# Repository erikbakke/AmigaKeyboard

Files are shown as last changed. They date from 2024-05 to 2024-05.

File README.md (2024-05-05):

# AmigaKeyboard
Replacement keyboard supporting MX-compatible switches, for all Amigas except A600 and A1200.

This keyboard design is based around an ATMega32U4 as keyboard controller, and is intended to be used as a replacement keyboards for Amigas with a keyboard controller on the keyboard.  This includes the A500, A1000, A2000, A3000 and A4000, including variants and towers.

The A600 and A1200 have the keyboard controller on the motherboard, and are not compatible with this keyboard design.

There are further notes in the Firmware and PCB folders, relevant to those parts of the project.

It should be noted that this is an early design, but I have built a keyboard up from scratch with this PCB and firmware and it is working on my A4000.
The design is not yet designed to fit into existing Amiga keyboard cases or as a 1:1 replacement for an A500 keyboard.  In order to achieve this, the mounting holes need to be adjusted to fit the external keyboard cases, and most likely a switch mounting plate will also be required.
To avoid disappointment, please keep this in mind before ordering PCBs from this design.

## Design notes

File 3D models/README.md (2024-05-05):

# 3D models

This folder contains 3D models associated with the Amiga replacement keyboard project

| Model | Description |
| ----- | --- |
| Amiga MX key stem adapter | Quick hack to allow putting original Amiga key caps on top of MX-compatible switches.  The keys are raised by about 7mm compared to a directly mounted key cap, so it may interfere with a keyboard case. |

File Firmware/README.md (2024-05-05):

# AmigaKeyboard firmware

This folder contains the firmware source code for the Amiga replacement keyboard project.

The firmware is written in C as an Atmel Studio project and maintained in the current version (Microchip Studio 7).
I have not found any protocol timing issues during the testing of the firmware, and I have used this with my A4000 for over a year without any problems.
However, that doesn't mean there are no problems when used with other Amiga models, so if any problems are found I am happy to rewrite the relevant sections in AVR assembly code in order to achieve better control over the timing.
I would prefer to keep parts of the code that are not timing sensitive in C, though, to keep the code readable and understandable even for users who do not have AVR experience.

The AVR ATMega32U4 was chosen for this project as it has enough IO pins to run the keyboard matrix and it has a USB port which should make firmware upgrades and debugging easier.
The current version of the firmware does not yet take advantage of the USB port, though.  This is at the top of my todo-list at the moment.

It should be noted here that the keyboard matrix is not laid out identically to Commodore's matrix and that some keys which had dedicated lines in the Commodore design form part of the matrix in this design.
The use of diodes to support n-key rollover should remove the need for dedicated lines, and I have not yet experienced any issues related to this.
Even though the matrix is laid out differently the resulting scan codes are, of course, the same as in the original design.

## Operating principle

The matrix is scanned repeatedly by setting each row output low in turn and then checking each column inputs go low.
If a low is detected, the row/column combination is looked up in a table of scancodes.
The firmware tracks the status of each key and at the end of the matrix scan it will send down/up codes to the Amiga for any keys with a changed status.
The Caps Lock key is tracked separately, as this key toggles state each time it is pressed.

The communication with the Amiga is a custom serial protocol described in the Amiga Hardware Reference Manual (See Appendix G in HRM, 3rd revision).

## Missing features

- Ability to act as a USB serial port for debugging purposes.
- Support firmware updates over USB.
- Ability to act as a USB keyboard, which would allow use with any USB-capable computer.

## Firmware flashing process

I am using an Atmel ICE programmer, using the AVR-ISP programming plug.
On revision 0.1 of the PCB, I have to solder Dupont M-M wires to the PCB for each line required for the programming, and I connect the other end of the wires to the AVR-ISP plug.
With revision 0.2, there is a footprint for an AVR-ISP socket on the PCB, and each programming signal is routed to this footprint to make programming easier.

## Change log

Revision 0.1:
- Initial version of the firmware
- Incomplete debugging support

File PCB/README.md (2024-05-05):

# AmigaKeyboard PCB files

This folder contains the schematics and PCB design for revision 0.2 of the Amiga replacement keyboard design as a KiCad project.  This was initially developed in KiCad 6, and is currently maintained in KiCad 7.

The keyboard works as is with my A4000, but I have not yet had a chance to test it with my A500.  The design should be electrically compatible, and I'm hoping it would be dimensionally compatible as well.
Some work will be required to fit the PCB to existing Amiga external keyboard housings.  The current design has mounting holes to fit a keyboard case I had lying around, so I would be very happy to receive positions and dimensions for mounting holes on the different Amiga keyboards for A2000, A3000 and A4000 models, and will update the design in any way I can to increase compatibility.

I am getting PCBs manufactured from time to time and still have some revision 0.1 PCBs left if anyone want one for experimenting.

## Change log
Revision 0.1:
- Initial PCB version for prototype board manufacture.
  
Revision 0.2:
- A missing trace between D180 and MX80 (numeric pad "4") has been fixed.  The bodge wire fix is no longer needed on revision 0.2.
- Added AVR ISP connector to assist in firmware upgrades and troubleshooting.

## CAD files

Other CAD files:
3D models/Amiga MX key stem adapter/Amiga MX key stem adapter before cut.blend
3D models/Amiga MX key stem adapter/Amiga MX key stem adapter.blend

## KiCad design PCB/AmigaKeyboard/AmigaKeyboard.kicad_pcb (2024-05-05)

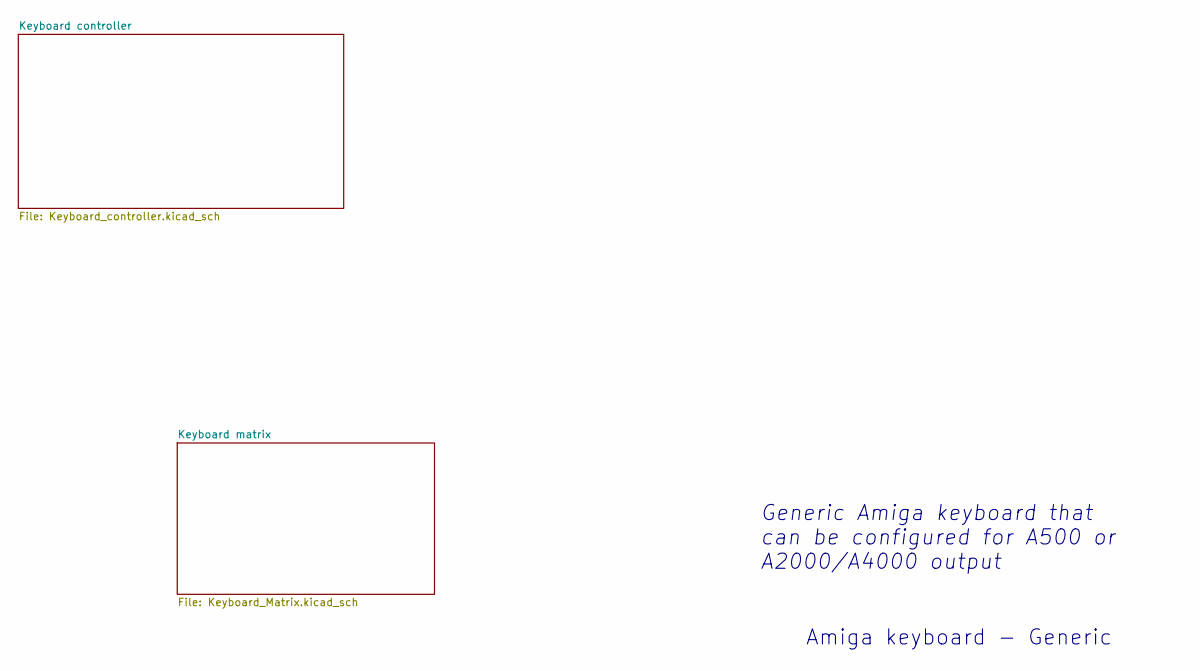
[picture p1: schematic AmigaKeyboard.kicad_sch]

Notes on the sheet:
Generic Amiga keyboard that can be configured for A500 or A2000/A4000 output
Amiga keyboard - Generic

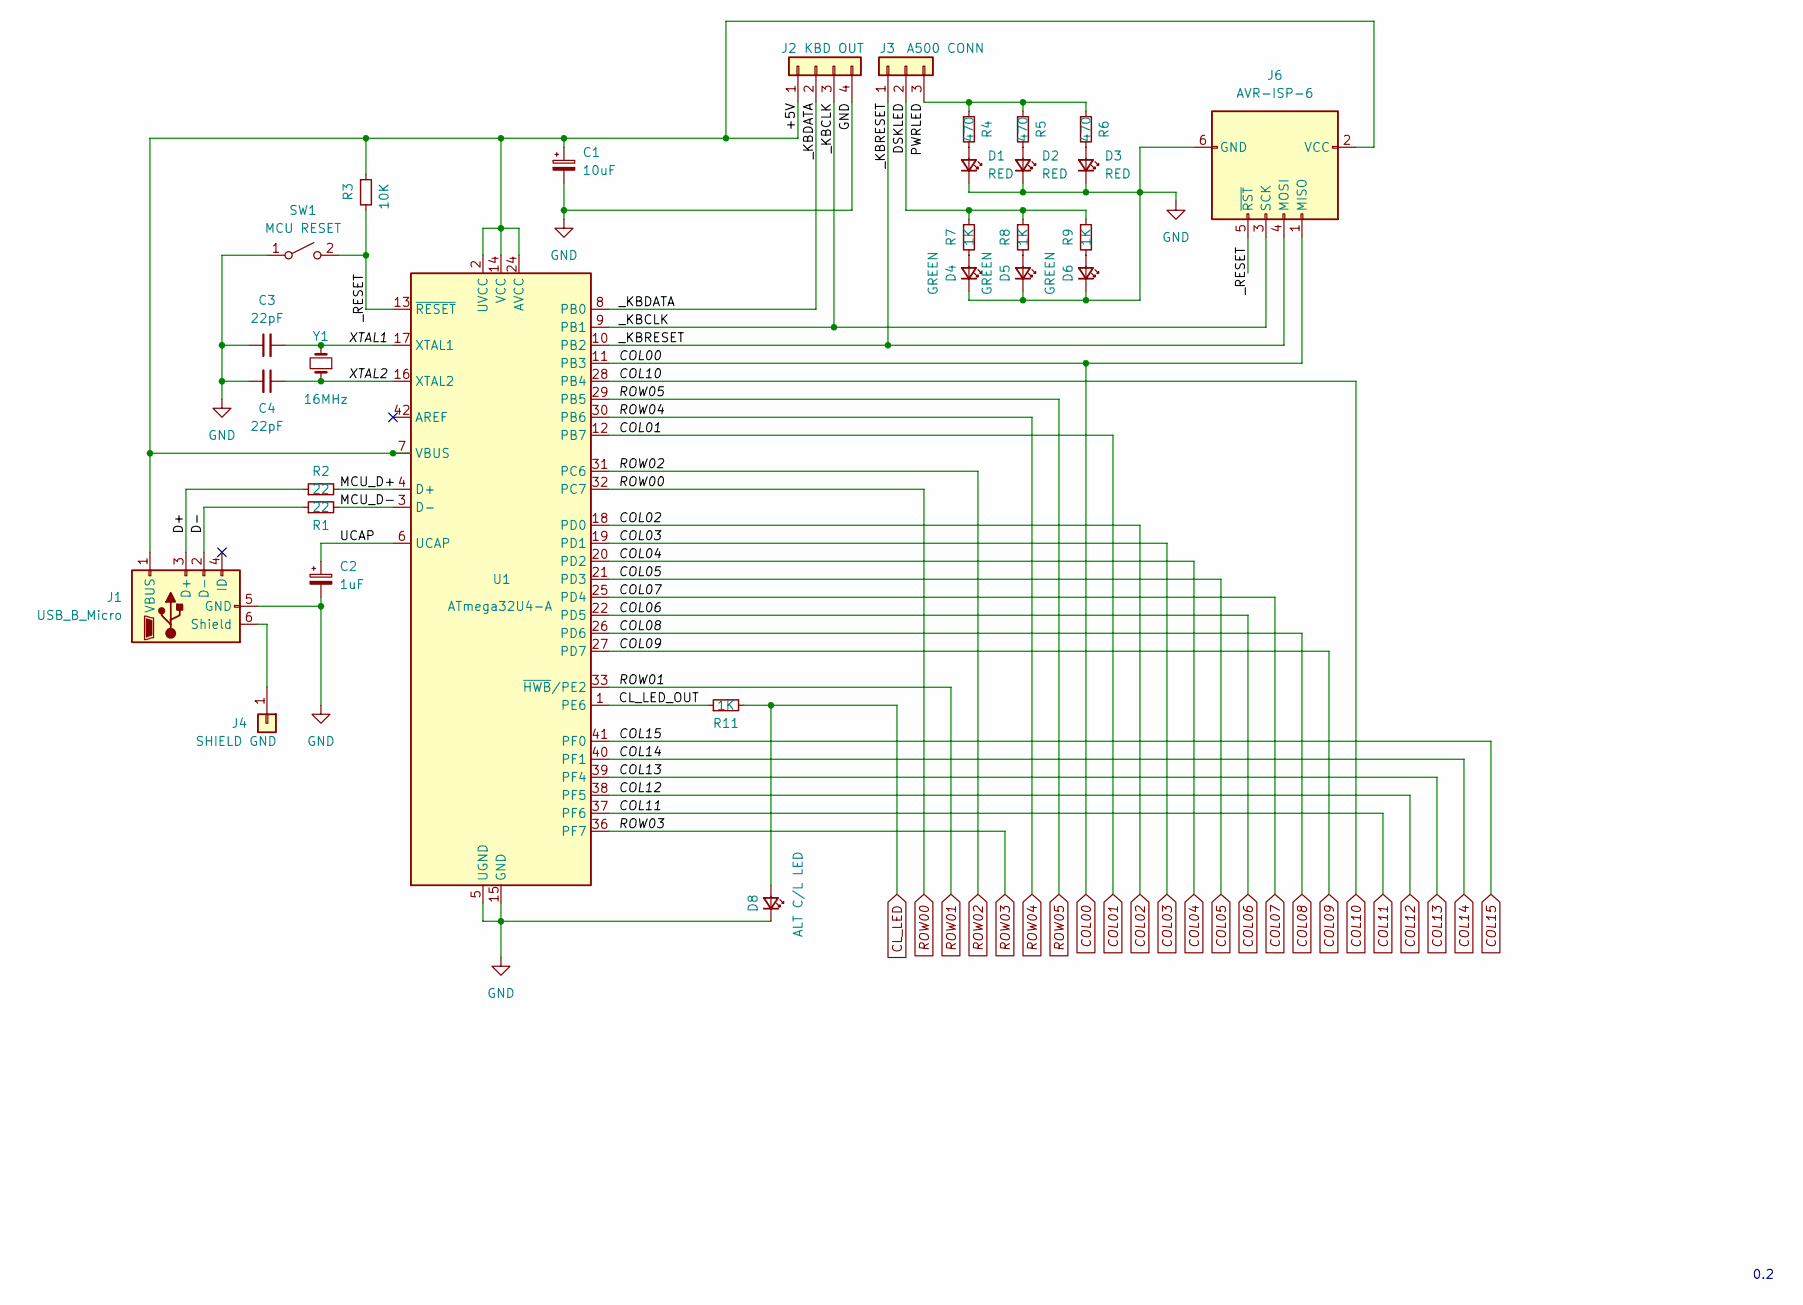
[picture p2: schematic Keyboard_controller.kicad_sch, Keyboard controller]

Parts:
C1: 10uF; CP_EIA-7343-31_Kemet-D
C2: 1uF; CP_EIA-3216-18_Kemet-A
C3, C4: 22pF; C_1206_3216Metric
D1, D2, D3: RED; LED_Rectangular_W5.0mm_H2.0mm
D4, D5, D6: GREEN; LED_Rectangular_W5.0mm_H2.0mm
D8: ALT C/L LED; LED_D3.0mm
J1: USB_B_Micro; USB_Micro-B_Wuerth_629105150521_CircularHoles
J2: KBD OUT; SolderWire-0.25sqmm_1x04_P4.2mm_D0.65mm_OD1.7mm
J3: A500 CONN; SolderWire-0.25sqmm_1x03_P4.2mm_D0.65mm_OD1.7mm
J4: SHIELD GND; SolderWire-2.5sqmm_1x01_D2.4mm_OD4.4mm
J6: AVR-ISP-6; PinHeader_2x03_P2.54mm_Vertical
R1, R2: 22; R_1206_3216Metric
R3: 10K; R_1206_3216Metric
R4, R5, R6: 470; R_1206_3216Metric
R7, R8, R9, R11: 1K; R_1206_3216Metric
SW1: MCU RESET; SW_PUSH_6mm
U1: ATmega32U4-A; TQFP-44_10x10mm_P0.8mm
Y1: 16MHz; Crystal_HC49-U_Vertical

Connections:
/Keyboard controller/+5V: C1.1, J1.1 (VBUS), J2.1, J6.2 (VCC), R3.1, U1.2 (UVCC), U1.7 (VBUS), U1.14 (VCC), U1.24 (AVCC), U1.34 (VCC), U1.44 (AVCC)
/Keyboard controller/CL_LED_OUT: R11.1, U1.1 (PE6)
/Keyboard controller/D+: J1.3 (D+), R2.1
/Keyboard controller/D-: J1.2 (D-), R1.1
/Keyboard controller/DSKLED: J3.2, R7.1, R8.1, R9.1
/Keyboard controller/MCU_D+: R2.2, U1.4 (D+)
/Keyboard controller/MCU_D-: R1.2, U1.3 (D-)
/Keyboard controller/PWRLED: J3.3, R4.1, R5.1, R6.1
/Keyboard controller/UCAP: C2.1, U1.6 (UCAP)
/Keyboard controller/XTAL1: C3.2, U1.17 (XTAL1), Y1.2
/Keyboard controller/XTAL2: C4.1, U1.16 (XTAL2), Y1.1
/Keyboard controller/_KBCLK: J2.3, J6.3 (SCK), U1.9 (PB1)
/Keyboard controller/_KBDATA: J2.2, U1.8 (PB0)
/Keyboard controller/_KBRESET: J3.1, J6.4 (MOSI), U1.10 (PB2)
/Keyboard controller/_RESET: J6.5 (~RST), R3.2, SW1.2 (B), U1.13 (~RESET)
CL_LED: D8.2 (A), R11.2; also elsewhere on the board
COL00: J6.1 (MISO), U1.11 (PB3); also elsewhere on the board
COL01: U1.12 (PB7); also elsewhere on the board
COL02: U1.18 (PD0); also elsewhere on the board
COL03: U1.19 (PD1); also elsewhere on the board
COL04: U1.20 (PD2); also elsewhere on the board
COL05: U1.21 (PD3); also elsewhere on the board
COL06: U1.22 (PD5); also elsewhere on the board
COL07: U1.25 (PD4); also elsewhere on the board
COL08: U1.26 (PD6); also elsewhere on the board
COL09: U1.27 (PD7); also elsewhere on the board
COL10: U1.28 (PB4); also elsewhere on the board
COL11: U1.37 (PF6); also elsewhere on the board
COL12: U1.38 (PF5); also elsewhere on the board
COL13: U1.39 (PF4); also elsewhere on the board
COL14: U1.40 (PF1); also elsewhere on the board
COL15: U1.41 (PF0); also elsewhere on the board
GND: C1.2, C2.2, C3.1, C4.2, D1.1 (K), D2.1 (K), D3.1 (K), D4.1 (K), D5.1 (K), D6.1 (K), D8.1 (K), J1.5 (GND), J2.4, J6.6 (GND), SW1.1 (A), U1.5 (UGND), U1.15 (GND), U1.23 (GND), U1.35 (GND), U1.43 (GND); also elsewhere on the board
unnamed: D1.2 (A), R4.2
unnamed: D2.2 (A), R5.2
unnamed: D3.2 (A), R6.2
unnamed: D4.2 (A), R7.2
unnamed: D5.2 (A), R8.2
unnamed: D6.2 (A), R9.2
unnamed: J1.6 (Shield), J4.1
ROW00: U1.32 (PC7); also elsewhere on the board
ROW01: U1.33 (~HWB/PE2); also elsewhere on the board
ROW02: U1.31 (PC6); also elsewhere on the board
ROW03: U1.36 (PF7); also elsewhere on the board
ROW04: U1.30 (PB6); also elsewhere on the board
ROW05: U1.29 (PB5); also elsewhere on the board

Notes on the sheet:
0.2

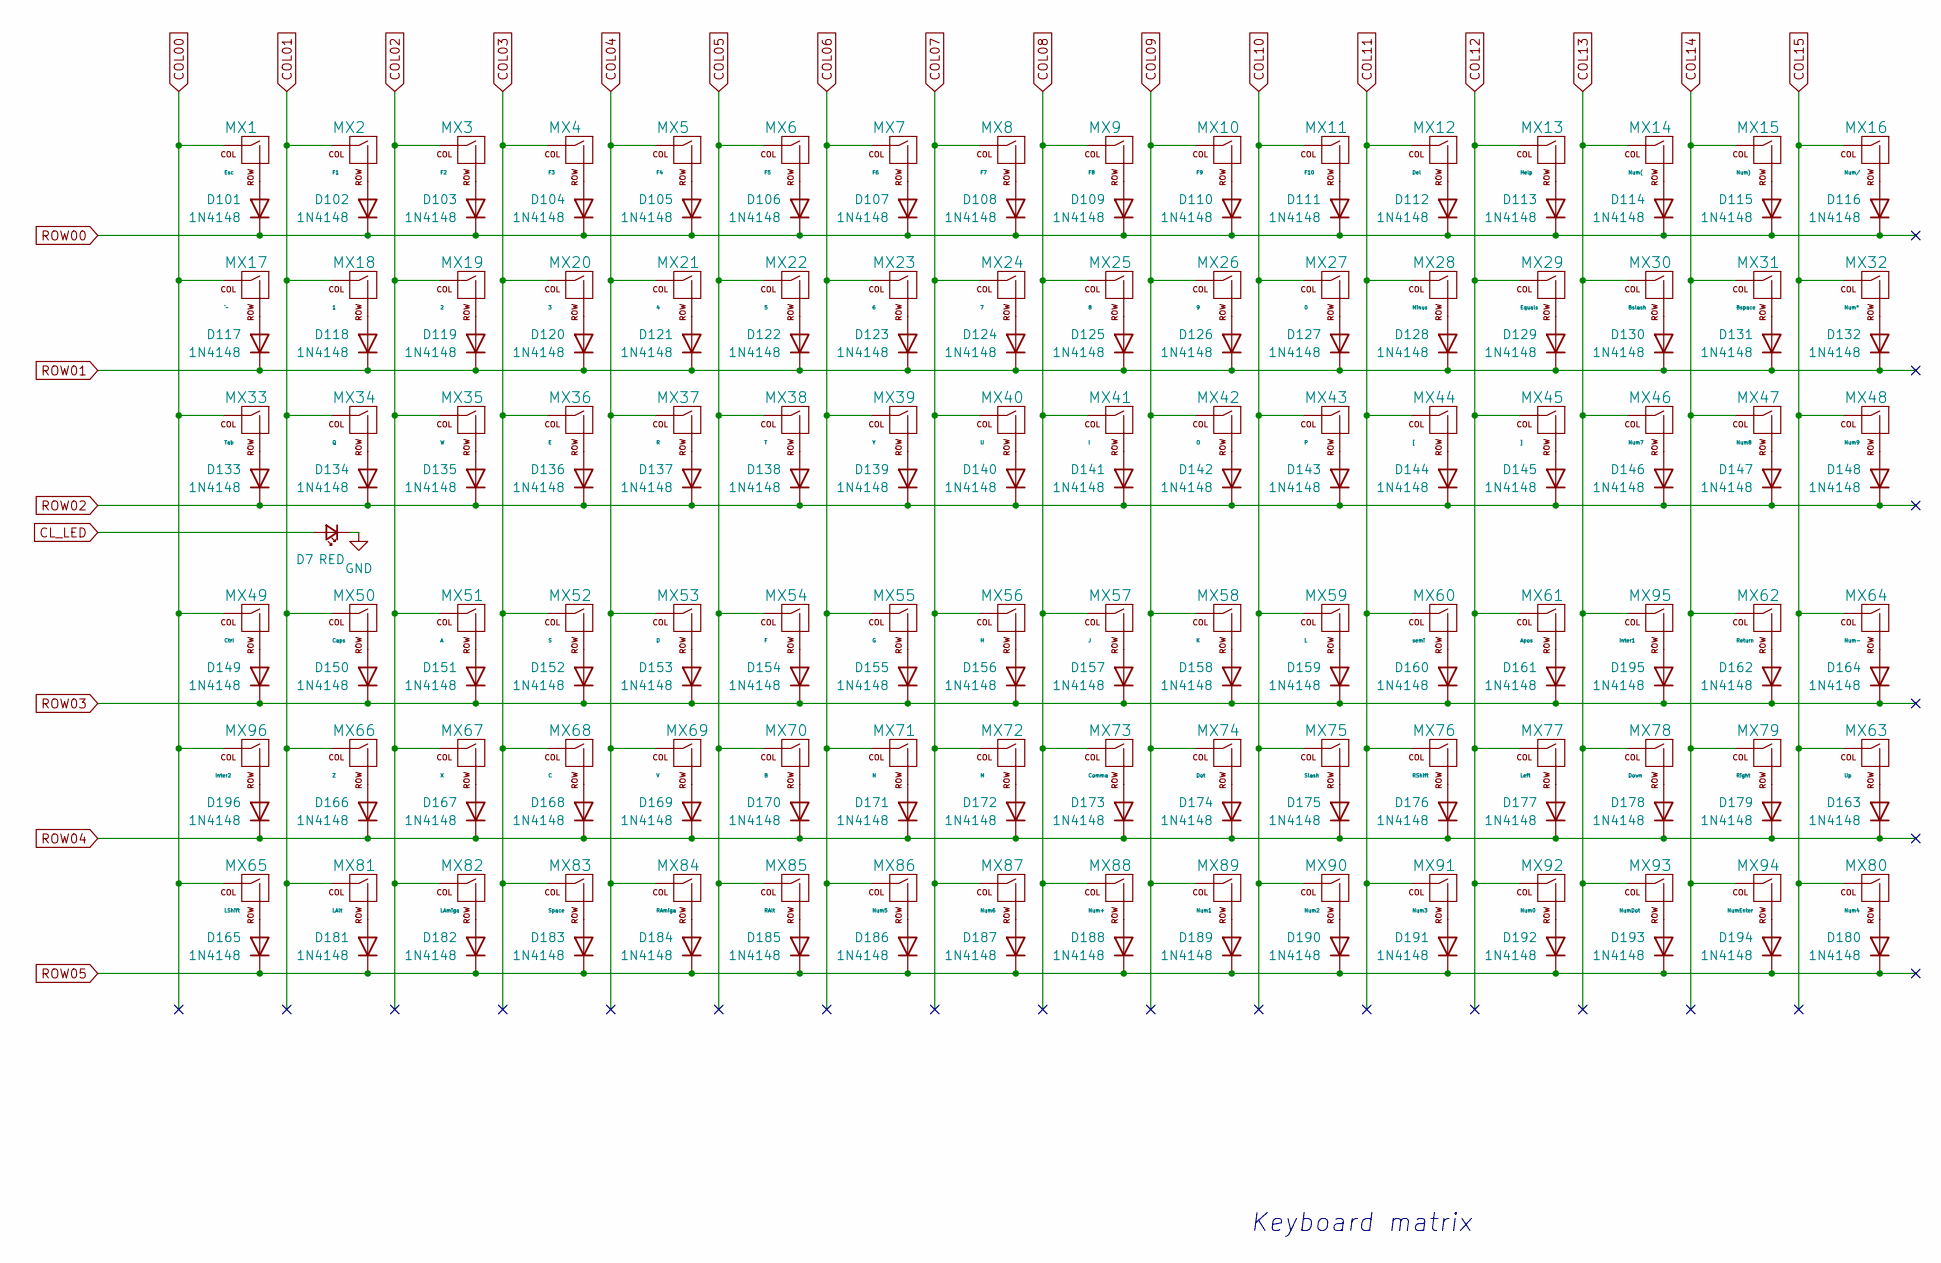
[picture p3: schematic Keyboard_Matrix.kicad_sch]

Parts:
D7: RED; LED_0805_2012Metric
D101, D102, D103, D104, D105, D106, D107, D108, D109, D110, D111, D112, D113, D114, D115, D116, D117, D118, D119, D120, D121, D122, D123, D124, D125, D126, D127, D128, D129, D130, D131, D132, D133, D134, D135, D136, D137, D138, D139, D140, D141, D142, D143, D144, D145, D146, D147, D148, D149, D150, D151, D152, D153, D154, D155, D156, D157, D158, D159, D160, D161, D162, D163, D164, D165, D166, D167, D168, D169, D170, D171, D172, D173, D174, D175, D176, D177, D178, D179, D180, D181, D182, D183, D184, D185, D186, D187, D188, D189, D190, D191, D192, D193, D194, D195, D196: 1N4148; D_0805_2012Metric_Pad1.15x1.40mm_HandSolder
MX1: Esc; SW_Cherry_MX_PCB_1.00u
MX2: F1; SW_Cherry_MX_PCB_1.25u
MX3: F2; SW_Cherry_MX_PCB_1.25u
MX4: F3; SW_Cherry_MX_PCB_1.25u
MX5: F4; SW_Cherry_MX_PCB_1.25u
MX6: F5; SW_Cherry_MX_PCB_1.25u
MX7: F6; SW_Cherry_MX_PCB_1.25u
MX8: F7; SW_Cherry_MX_PCB_1.25u
MX9: F8; SW_Cherry_MX_PCB_1.25u
MX10: F9; SW_Cherry_MX_PCB_1.25u
MX11: F10; SW_Cherry_MX_PCB_1.25u
MX12: Del; SW_Cherry_MX_PCB_1.50u
MX13: Help; SW_Cherry_MX_PCB_1.50u
MX14: Num(; SW_Cherry_MX_PCB_1.00u
MX15: Num); SW_Cherry_MX_PCB_1.00u
MX16: Num/; SW_Cherry_MX_PCB_1.00u
MX17: `~; SW_Cherry_MX_PCB_1.50u
MX18: 1; SW_Cherry_MX_PCB_1.00u
MX19: 2; SW_Cherry_MX_PCB_1.00u
MX20: 3; SW_Cherry_MX_PCB_1.00u
MX21: 4; SW_Cherry_MX_PCB_1.00u
MX22: 5; SW_Cherry_MX_PCB_1.00u
MX23: 6; SW_Cherry_MX_PCB_1.00u
MX24: 7; SW_Cherry_MX_PCB_1.00u
MX25: 8; SW_Cherry_MX_PCB_1.00u
MX26: 9; SW_Cherry_MX_PCB_1.00u
MX27: 0; SW_Cherry_MX_PCB_1.00u
MX28: Minus; SW_Cherry_MX_PCB_1.00u
MX29: Equals; SW_Cherry_MX_PCB_1.00u
MX30: Bslash; SW_Cherry_MX_PCB_1.00u
MX31: Bspace; SW_Cherry_MX_PCB_1.00u
MX32: Num*; SW_Cherry_MX_PCB_1.00u
MX33: Tab; SW_Cherry_MX_PCB_2.00u
MX34: Q; SW_Cherry_MX_PCB_1.00u
MX35: W; SW_Cherry_MX_PCB_1.00u
MX36: E; SW_Cherry_MX_PCB_1.00u
MX37: R; SW_Cherry_MX_PCB_1.00u
MX38: T; SW_Cherry_MX_PCB_1.00u
MX39: Y; SW_Cherry_MX_PCB_1.00u
MX40: U; SW_Cherry_MX_PCB_1.00u
MX41: I; SW_Cherry_MX_PCB_1.00u
MX42: O; SW_Cherry_MX_PCB_1.00u
MX43: P; SW_Cherry_MX_PCB_1.00u
MX44: [; SW_Cherry_MX_PCB_1.00u
MX45: ]; SW_Cherry_MX_PCB_1.00u
MX46: Num7; SW_Cherry_MX_PCB_1.00u
MX47: Num8; SW_Cherry_MX_PCB_1.00u
MX48: Num9; SW_Cherry_MX_PCB_1.00u
MX49: Ctrl; SW_Cherry_MX_PCB_1.25u
MX50: Caps; SW_Cherry_MX_PCB_1.00u
MX51: A; SW_Cherry_MX_PCB_1.00u
MX52: S; SW_Cherry_MX_PCB_1.00u
MX53: D; SW_Cherry_MX_PCB_1.00u
MX54: F; SW_Cherry_MX_PCB_1.00u
MX55: G; SW_Cherry_MX_PCB_1.00u
MX56: H; SW_Cherry_MX_PCB_1.00u
MX57: J; SW_Cherry_MX_PCB_1.00u
MX58: K; SW_Cherry_MX_PCB_1.00u
MX59: L; SW_Cherry_MX_PCB_1.00u
MX60: semi; SW_Cherry_MX_PCB_1.00u
MX61: Apos; SW_Cherry_MX_PCB_1.00u
MX62: Return; SW_Cherry_MX_PCB_ISOEnter
MX63: Up; SW_Cherry_MX_PCB_1.00u
MX64: Num-; SW_Cherry_MX_PCB_1.00u
MX65: LShift; SW_Cherry_MX_PCB_1.75u
MX66: Z; SW_Cherry_MX_PCB_1.00u
MX67: X; SW_Cherry_MX_PCB_1.00u
MX68: C; SW_Cherry_MX_PCB_1.00u
MX69: V; SW_Cherry_MX_PCB_1.00u
MX70: B; SW_Cherry_MX_PCB_1.00u
MX71: N; SW_Cherry_MX_PCB_1.00u
MX72: M; SW_Cherry_MX_PCB_1.00u
MX73: Comma; SW_Cherry_MX_PCB_1.00u
MX74: Dot; SW_Cherry_MX_PCB_1.00u
MX75: Slash; SW_Cherry_MX_PCB_1.00u
MX76: RShift; SW_Cherry_MX_PCB_2.50u
MX77: Left; SW_Cherry_MX_PCB_1.00u
MX78: Down; SW_Cherry_MX_PCB_1.00u
MX79: Right; SW_Cherry_MX_PCB_1.00u
MX80: Num4; SW_Cherry_MX_PCB_1.00u
MX81: LAlt; SW_Cherry_MX_PCB_1.25u
MX82: LAmiga; SW_Cherry_MX_PCB_1.25u
MX83: Space; SW_Cherry_MX_PCB_9.00u
MX84: RAmiga; SW_Cherry_MX_PCB_1.25u
MX85: RAlt; SW_Cherry_MX_PCB_1.25u
MX86: Num5; SW_Cherry_MX_PCB_1.00u
MX87: Num6; SW_Cherry_MX_PCB_1.00u
MX88: Num+; SW_Cherry_MX_PCB_1.00u
MX89: Num1; SW_Cherry_MX_PCB_1.00u
MX90: Num2; SW_Cherry_MX_PCB_1.00u
MX91: Num3; SW_Cherry_MX_PCB_1.00u
MX92: Num0; SW_Cherry_MX_PCB_2.00u
MX93: NumDot; SW_Cherry_MX_PCB_1.00u
MX94: NumEnter; SW_Cherry_MX_PCB_2.00u_90deg
MX95: Inter1; SW_Cherry_MX_PCB_1.00u
MX96: Inter2; SW_Cherry_MX_PCB_1.00u

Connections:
CL_LED: D7.2 (A); also elsewhere on the board
COL00: MX1.1 (COL), MX17.1 (COL), MX33.1 (COL), MX49.1 (COL), MX65.1 (COL), MX96.1 (COL); also elsewhere on the board
COL01: MX2.1 (COL), MX18.1 (COL), MX34.1 (COL), MX50.1 (COL), MX66.1 (COL), MX81.1 (COL); also elsewhere on the board
COL02: MX3.1 (COL), MX19.1 (COL), MX35.1 (COL), MX51.1 (COL), MX67.1 (COL), MX82.1 (COL); also elsewhere on the board
COL03: MX4.1 (COL), MX20.1 (COL), MX36.1 (COL), MX52.1 (COL), MX68.1 (COL), MX83.1 (COL); also elsewhere on the board
COL04: MX5.1 (COL), MX21.1 (COL), MX37.1 (COL), MX53.1 (COL), MX69.1 (COL), MX84.1 (COL); also elsewhere on the board
COL05: MX6.1 (COL), MX22.1 (COL), MX38.1 (COL), MX54.1 (COL), MX70.1 (COL), MX85.1 (COL); also elsewhere on the board
COL06: MX7.1 (COL), MX23.1 (COL), MX39.1 (COL), MX55.1 (COL), MX71.1 (COL), MX86.1 (COL); also elsewhere on the board
COL07: MX8.1 (COL), MX24.1 (COL), MX40.1 (COL), MX56.1 (COL), MX72.1 (COL), MX87.1 (COL); also elsewhere on the board
COL08: MX9.1 (COL), MX25.1 (COL), MX41.1 (COL), MX57.1 (COL), MX73.1 (COL), MX88.1 (COL); also elsewhere on the board
COL09: MX10.1 (COL), MX26.1 (COL), MX42.1 (COL), MX58.1 (COL), MX74.1 (COL), MX89.1 (COL); also elsewhere on the board
COL10: MX11.1 (COL), MX27.1 (COL), MX43.1 (COL), MX59.1 (COL), MX75.1 (COL), MX90.1 (COL); also elsewhere on the board
COL11: MX12.1 (COL), MX28.1 (COL), MX44.1 (COL), MX60.1 (COL), MX76.1 (COL), MX91.1 (COL); also elsewhere on the board
COL12: MX13.1 (COL), MX29.1 (COL), MX45.1 (COL), MX61.1 (COL), MX77.1 (COL), MX92.1 (COL); also elsewhere on the board
COL13: MX14.1 (COL), MX30.1 (COL), MX46.1 (COL), MX78.1 (COL), MX93.1 (COL), MX95.1 (COL); also elsewhere on the board
COL14: MX15.1 (COL), MX31.1 (COL), MX47.1 (COL), MX62.1 (COL), MX79.1 (COL), MX94.1 (COL); also elsewhere on the board
COL15: MX16.1 (COL), MX32.1 (COL), MX48.1 (COL), MX63.1 (COL), MX64.1 (COL), MX80.1 (COL); also elsewhere on the board
GND: D7.1 (K); also elsewhere on the board
unnamed: D101.2 (A), MX1.2 (ROW)
unnamed: D102.2 (A), MX2.2 (ROW)
unnamed: D103.2 (A), MX3.2 (ROW)
unnamed: D104.2 (A), MX4.2 (ROW)
unnamed: D105.2 (A), MX5.2 (ROW)
unnamed: D106.2 (A), MX6.2 (ROW)
unnamed: D107.2 (A), MX7.2 (ROW)
unnamed: D108.2 (A), MX8.2 (ROW)
unnamed: D109.2 (A), MX9.2 (ROW)
unnamed: D110.2 (A), MX10.2 (ROW)
unnamed: D111.2 (A), MX11.2 (ROW)
unnamed: D112.2 (A), MX12.2 (ROW)
unnamed: D113.2 (A), MX13.2 (ROW)
unnamed: D114.2 (A), MX14.2 (ROW)
unnamed: D115.2 (A), MX15.2 (ROW)
unnamed: D116.2 (A), MX16.2 (ROW)
unnamed: D117.2 (A), MX17.2 (ROW)
unnamed: D118.2 (A), MX18.2 (ROW)
unnamed: D119.2 (A), MX19.2 (ROW)
unnamed: D120.2 (A), MX20.2 (ROW)
unnamed: D121.2 (A), MX21.2 (ROW)
unnamed: D122.2 (A), MX22.2 (ROW)
unnamed: D123.2 (A), MX23.2 (ROW)
unnamed: D124.2 (A), MX24.2 (ROW)
unnamed: D125.2 (A), MX25.2 (ROW)
unnamed: D126.2 (A), MX26.2 (ROW)
unnamed: D127.2 (A), MX27.2 (ROW)
unnamed: D128.2 (A), MX28.2 (ROW)
unnamed: D129.2 (A), MX29.2 (ROW)
unnamed: D130.2 (A), MX30.2 (ROW)
unnamed: D131.2 (A), MX31.2 (ROW)
unnamed: D132.2 (A), MX32.2 (ROW)
unnamed: D133.2 (A), MX33.2 (ROW)
unnamed: D134.2 (A), MX34.2 (ROW)
unnamed: D135.2 (A), MX35.2 (ROW)
unnamed: D136.2 (A), MX36.2 (ROW)
unnamed: D137.2 (A), MX37.2 (ROW)
unnamed: D138.2 (A), MX38.2 (ROW)
unnamed: D139.2 (A), MX39.2 (ROW)
unnamed: D140.2 (A), MX40.2 (ROW)
unnamed: D141.2 (A), MX41.2 (ROW)
unnamed: D142.2 (A), MX42.2 (ROW)
unnamed: D143.2 (A), MX43.2 (ROW)
unnamed: D144.2 (A), MX44.2 (ROW)
unnamed: D145.2 (A), MX45.2 (ROW)
unnamed: D146.2 (A), MX46.2 (ROW)
unnamed: D147.2 (A), MX47.2 (ROW)
unnamed: D148.2 (A), MX48.2 (ROW)
unnamed: D149.2 (A), MX49.2 (ROW)
unnamed: D150.2 (A), MX50.2 (ROW)
unnamed: D151.2 (A), MX51.2 (ROW)
unnamed: D152.2 (A), MX52.2 (ROW)
unnamed: D153.2 (A), MX53.2 (ROW)
unnamed: D154.2 (A), MX54.2 (ROW)
unnamed: D155.2 (A), MX55.2 (ROW)
unnamed: D156.2 (A), MX56.2 (ROW)
unnamed: D157.2 (A), MX57.2 (ROW)
unnamed: D158.2 (A), MX58.2 (ROW)
unnamed: D159.2 (A), MX59.2 (ROW)
unnamed: D160.2 (A), MX60.2 (ROW)
unnamed: D161.2 (A), MX61.2 (ROW)
unnamed: D162.2 (A), MX62.2 (ROW)
unnamed: D163.2 (A), MX63.2 (ROW)
unnamed: D164.2 (A), MX64.2 (ROW)
unnamed: D165.2 (A), MX65.2 (ROW)
unnamed: D166.2 (A), MX66.2 (ROW)
unnamed: D167.2 (A), MX67.2 (ROW)
unnamed: D168.2 (A), MX68.2 (ROW)
unnamed: D169.2 (A), MX69.2 (ROW)
unnamed: D170.2 (A), MX70.2 (ROW)
unnamed: D171.2 (A), MX71.2 (ROW)
unnamed: D172.2 (A), MX72.2 (ROW)
unnamed: D173.2 (A), MX73.2 (ROW)
unnamed: D174.2 (A), MX74.2 (ROW)
unnamed: D175.2 (A), MX75.2 (ROW)
unnamed: D176.2 (A), MX76.2 (ROW)
unnamed: D177.2 (A), MX77.2 (ROW)
unnamed: D178.2 (A), MX78.2 (ROW)
unnamed: D179.2 (A), MX79.2 (ROW)
unnamed: D180.2 (A), MX80.2 (ROW)
unnamed: D181.2 (A), MX81.2 (ROW)
unnamed: D182.2 (A), MX82.2 (ROW)
unnamed: D183.2 (A), MX83.2 (ROW)
unnamed: D184.2 (A), MX84.2 (ROW)
unnamed: D185.2 (A), MX85.2 (ROW)
unnamed: D186.2 (A), MX86.2 (ROW)
unnamed: D187.2 (A), MX87.2 (ROW)
unnamed: D188.2 (A), MX88.2 (ROW)
unnamed: D189.2 (A), MX89.2 (ROW)
unnamed: D190.2 (A), MX90.2 (ROW)
unnamed: D191.2 (A), MX91.2 (ROW)
unnamed: D192.2 (A), MX92.2 (ROW)
unnamed: D193.2 (A), MX93.2 (ROW)
unnamed: D194.2 (A), MX94.2 (ROW)
unnamed: D195.2 (A), MX95.2 (ROW)
unnamed: D196.2 (A), MX96.2 (ROW)
ROW00: D101.1 (K), D102.1 (K), D103.1 (K), D104.1 (K), D105.1 (K), D106.1 (K), D107.1 (K), D108.1 (K), D109.1 (K), D110.1 (K), D111.1 (K), D112.1 (K), D113.1 (K), D114.1 (K), D115.1 (K), D116.1 (K); also elsewhere on the board
ROW01: D117.1 (K), D118.1 (K), D119.1 (K), D120.1 (K), D121.1 (K), D122.1 (K), D123.1 (K), D124.1 (K), D125.1 (K), D126.1 (K), D127.1 (K), D128.1 (K), D129.1 (K), D130.1 (K), D131.1 (K), D132.1 (K); also elsewhere on the board
ROW02: D133.1 (K), D134.1 (K), D135.1 (K), D136.1 (K), D137.1 (K), D138.1 (K), D139.1 (K), D140.1 (K), D141.1 (K), D142.1 (K), D143.1 (K), D144.1 (K), D145.1 (K), D146.1 (K), D147.1 (K), D148.1 (K); also elsewhere on the board
ROW03: D149.1 (K), D150.1 (K), D151.1 (K), D152.1 (K), D153.1 (K), D154.1 (K), D155.1 (K), D156.1 (K), D157.1 (K), D158.1 (K), D159.1 (K), D160.1 (K), D161.1 (K), D162.1 (K), D164.1 (K), D195.1 (K); also elsewhere on the board
ROW04: D163.1 (K), D166.1 (K), D167.1 (K), D168.1 (K), D169.1 (K), D170.1 (K), D171.1 (K), D172.1 (K), D173.1 (K), D174.1 (K), D175.1 (K), D176.1 (K), D177.1 (K), D178.1 (K), D179.1 (K), D196.1 (K); also elsewhere on the board
ROW05: D165.1 (K), D180.1 (K), D181.1 (K), D182.1 (K), D183.1 (K), D184.1 (K), D185.1 (K), D186.1 (K), D187.1 (K), D188.1 (K), D189.1 (K), D190.1 (K), D191.1 (K), D192.1 (K), D193.1 (K), D194.1 (K); also elsewhere on the board

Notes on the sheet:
Keyboard matrix

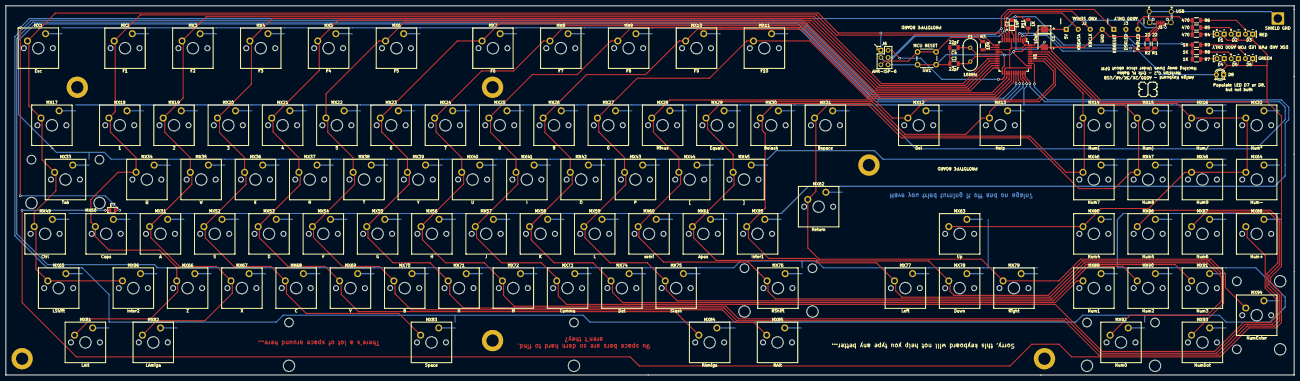
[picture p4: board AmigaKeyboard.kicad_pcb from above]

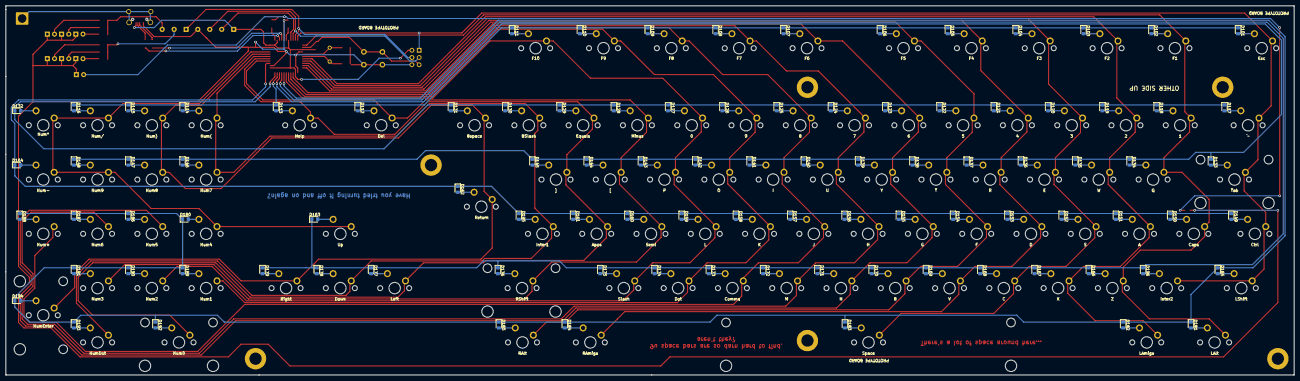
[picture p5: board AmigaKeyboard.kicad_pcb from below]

Board: 2 copper layers, 452.1 x 129.5 mm, 233 parts (96 on the bottom side), 142 nets.

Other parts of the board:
MNT01, MNT02, MNT03, MNT04, MNT05, MNT07: MountingHole_4.3mm_M4_DIN965_Pad
STAB01: Stabilizer_Cherry_MX_6.25u
STAB02, STAB02#2, STAB02#3, STAB02#4: Stabilizer_Cherry_MX_2.00u

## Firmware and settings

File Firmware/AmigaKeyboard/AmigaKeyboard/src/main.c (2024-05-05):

/**
 * \file
 *
 * \brief Empty user application template
 *
 */

/**
 * \mainpage User Application template doxygen documentation
 *
 * \par Empty user application template
 *
 * Bare minimum empty user application template
 *
 * \par Content
 *
 * -# Include the ASF header files (through asf.h)
 * -# "Insert system clock initialization code here" comment
 * -# Minimal main function that starts with a call to board_init()
 * -# "Insert application code here" comment
 *
 */

/*
 * Include header files for all drivers that have been imported from
 * Atmel Software Framework (ASF).
 */
/*
 * Support and FAQ: visit <a href="https://www.microchip.com/support/">Microchip Support</a>
 */
#include <asf.h>

#include "../keyboard.h"

int main( void )
{
	sysclk_init();
	board_init();

	/* Insert application code here, after the board has been initialized. */
	keyboard_init();
	
	while( true )
	{
		scanMatrix();
	}
}

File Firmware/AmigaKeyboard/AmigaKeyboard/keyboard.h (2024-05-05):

/*
 * keyboard.h
 *
 * Created: 14/01/2022 12:17:07
 *  Author: ebakke
 */ 

#include <avr/io.h>

#ifndef KEYBOARD_H_
#define KEYBOARD_H_

#define NUM_ROWS	( 6 )
#define NUM_COLS	( 16 )

// Keyboard serial
#define KBDATA_OUT		( PORTB )
#define KBDATA_IN		( PINB )
#define KBDATA_DDR		( DDRB )
#define KBDATA_PIN		( 0 )
#define KBDATA_MASK		( 1 << KBDATA_PIN )

#define KBCLK_OUT		( PORTB )
#define KBCLK_DDR		( DDRB )
#define KBCLK_PIN		( 1 )
#define KBCLK_MASK		( 1 << KBCLK_PIN )

#define KBRESET_OUT		( PORTB )
#define KBRESET_DDR		( DDRB )
#define KBRESET_PIN		( 2 )
#define KBRESET_MASK	( 1 << KBRESET_PIN )

// Column signals
#define COL00_IN		( PINB )
#define COL00_DDR		( DDRB )
#define COL00_PIN		( 3 )
#define COL00_MASK		( 1 << COL00_PIN )

#define COL01_IN		( PINB )
#define COL01_DDR		( DDRB )
#define COL01_PIN		( 7 )
#define COL01_MASK		( 1 << COL01_PIN )

#define COL02_IN		( PIND )
#define COL02_DDR		( DDRD )
#define COL02_PIN		( 0 )
#define COL02_MASK		( 1 << COL02_PIN )

#define COL03_IN		( PIND )
#define COL03_DDR		( DDRD )
#define COL03_PIN		( 1 )
#define COL03_MASK		( 1 << COL03_PIN )

#define COL04_IN		( PIND )
#define COL04_DDR		( DDRD )
#define COL04_PIN		( 2 )
#define COL04_MASK		( 1 << COL04_PIN )

#define COL05_IN		( PIND )
#define COL05_DDR		( DDRD )
#define COL05_PIN		( 3 )
#define COL05_MASK		( 1 << COL05_PIN )

#define COL06_IN		( PIND )
#define COL06_DDR		( DDRD )
#define COL06_PIN		( 5 )
#define COL06_MASK		( 1 << COL06_PIN )

#define COL07_IN		( PIND )
#define COL07_DDR		( DDRD )
#define COL07_PIN		( 4 )
#define COL07_MASK		( 1 << COL07_PIN )

#define COL08_IN		( PIND )
#define COL08_DDR		( DDRD )
#define COL08_PIN		( 6 )
#define COL08_MASK		( 1 << COL08_PIN )

#define COL09_IN		( PIND )
#define COL09_DDR		( DDRD )
#define COL09_PIN		( 7 )
#define COL09_MASK		( 1 << COL09_PIN )

#define COL10_IN		( PINB )
#define COL10_DDR		( DDRB )
#define COL10_PIN		( 4 )
#define COL10_MASK		( 1 << COL10_PIN )

#define COL11_IN		( PINF )
#define COL11_DDR		( DDRF )
#define COL11_PIN		( 6 )
#define COL11_MASK		( 1 << COL11_PIN )

#define COL12_IN		( PINF )
#define COL12_DDR		( DDRF )
#define COL12_PIN		( 5 )
#define COL12_MASK		( 1 << COL12_PIN )

#define COL13_IN		( PINF )
#define COL13_DDR		( DDRF )
#define COL13_PIN		( 4 )
#define COL13_MASK		( 1 << COL13_PIN )

#define COL14_IN		( PINF )
#define COL14_DDR		( DDRF )
#define COL14_PIN		( 1 )
#define COL14_MASK		( 1 << COL14_PIN )

#define COL15_IN		( PINF )
#define COL15_DDR		( DDRF )
#define COL15_PIN		( 0 )
#define COL15_MASK		( 1 << COL15_PIN )

// Row signals
#define ROW00_OUT		( PORTC )
#define ROW00_DDR		( DDRC )
#define ROW00_PIN		( 7 )
#define ROW00_MASK		( 1 << ROW00_PIN )

#define ROW01_OUT		( PORTE )
#define ROW01_DDR		( DDRE )
#define ROW01_PIN		( 2 )
#define ROW01_MASK		( 1 << ROW01_PIN )

#define ROW02_OUT		( PORTC )
#define ROW02_DDR		( DDRC )
#define ROW02_PIN		( 6 )
#define ROW02_MASK		( 1 << ROW02_PIN )

#define ROW03_OUT		( PORTF )
#define ROW03_DDR		( DDRF )
#define ROW03_PIN		( 7 )
#define ROW03_MASK		( 1 << ROW03_PIN )

#define ROW04_OUT		( PORTB )
#define ROW04_DDR		( DDRB )
#define ROW04_PIN		( 6 )
#define ROW04_MASK		( 1 << ROW04_PIN )

#define ROW05_OUT		( PORTB )
#define ROW05_DDR		( DDRB )
#define ROW05_PIN		( 5 )
#define ROW05_MASK		( 1 << ROW05_PIN )

// Caps Lock
#define CAPS_OUT		( PORTE )
#define CAPS_DDR		( DDRE )
#define CAPS_PIN		( 6 )
#define CAPS_MASK		( 1 << CAPS_PIN )
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

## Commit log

2024-05-05 Adding current PCB design and schematics
    [AmigaKeyboard.kicad_pcb, AmigaKeyboard.kicad_sch, Keyboard_Matrix.kicad_sch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]
2024-05-05 Create README for PCB design.md
2024-05-05 Add 3D models folder
    [Amiga MX key stem adapter before cut.blend, Amiga MX key stem adapter.blend]
